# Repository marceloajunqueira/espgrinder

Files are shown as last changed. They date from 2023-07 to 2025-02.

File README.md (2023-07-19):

# Espgrinder

Espgrider is a kit to convert your manual coffee grinder into electric using very cheap parts. The software is based on the powefull ESPHome project.

The main goal is to convert very good manual coffee grinder into 2 in 1 Grind by Weight hardware. Also the hardware need to be used without any risk of demage, simulating the same torque and force used in hand grinding.

The motor is the "Mabuchi" standard that is commom used for car power window.

**There are two versions available:**
1. Without eletronics: Just the base with an On/Off switch, simple and direct. You only need a 3D printer and some soldering skills
2. Eletronic controlled by ESP32: The magic of software, with the eletronic you will be able to control speed, timer and even have a precise digital scale.

** Features for the electronic version**
1. Simple User Interface using SSD1306 display
2. PWM motor control
3. Timer to control grind speed
4. Precision digital scale
5. Over the Air firmware updates
6. Grind by Weight (Under development)

**Supported Grinders:**
You can use any grinder with 1/4 Hex shaft, only the support need to be adjusted
Included supports for:
 - Kingrinder K4 / K6

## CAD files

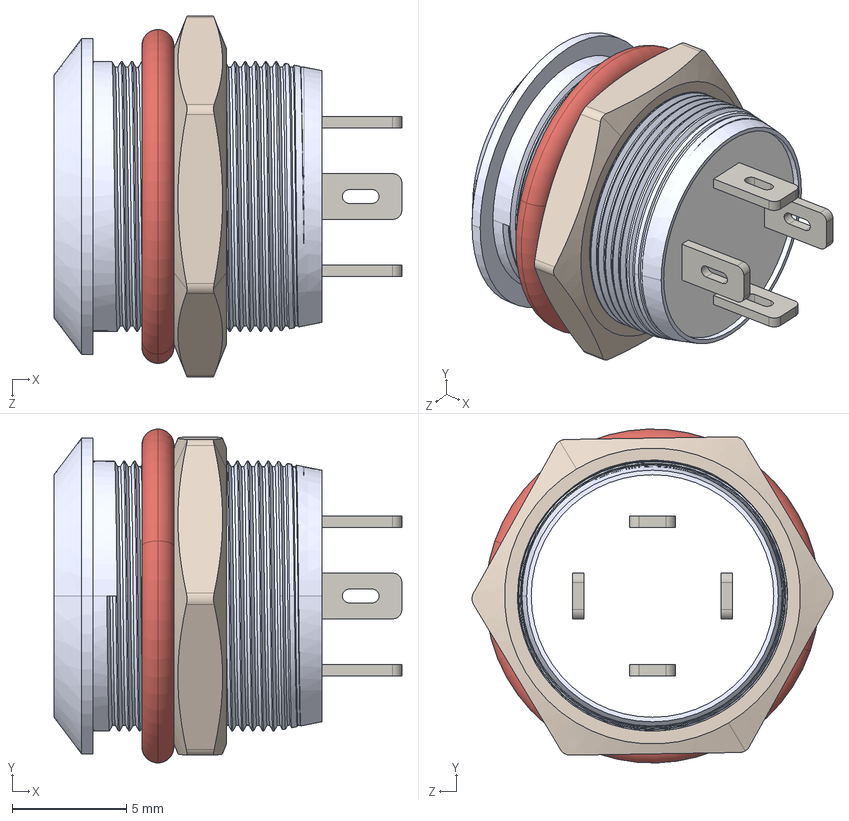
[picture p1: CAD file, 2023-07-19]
3D Model/Components/Push_btn_asm.STEP
15.2 x 14.6 x 15.8 mm
Push_btn
Push_btn_nut
Sealing_ring

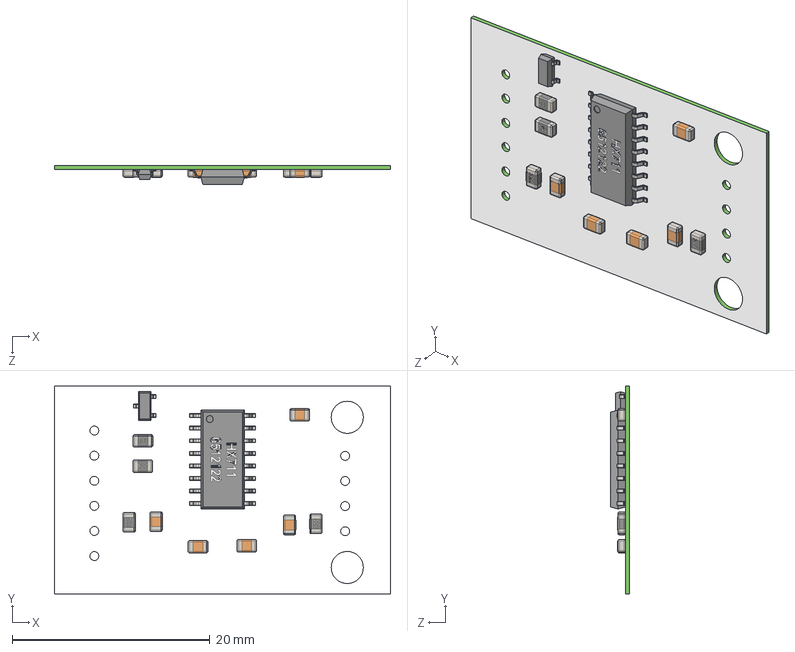
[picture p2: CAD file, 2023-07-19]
3D Model/Components/HX711.STEP
34.0 x 21.0 x 1.97 mm
placa_Valor predeterminado
base_HX711_Valor predeterminado
pino_HX711_Valor predeterminado x 16
RESISTOR_SMD_122_Valor predeterminado x 2
RESISTOR_SMD_822_Valor predeterminado
RESISTOR_SMD_203_Valor predeterminado
CAPACITOR_805_Valor predeterminado x 5
TRANSISTOR_SOT23_Valor predeterminado
PINO_SOT23_Valor predeterminado x 3

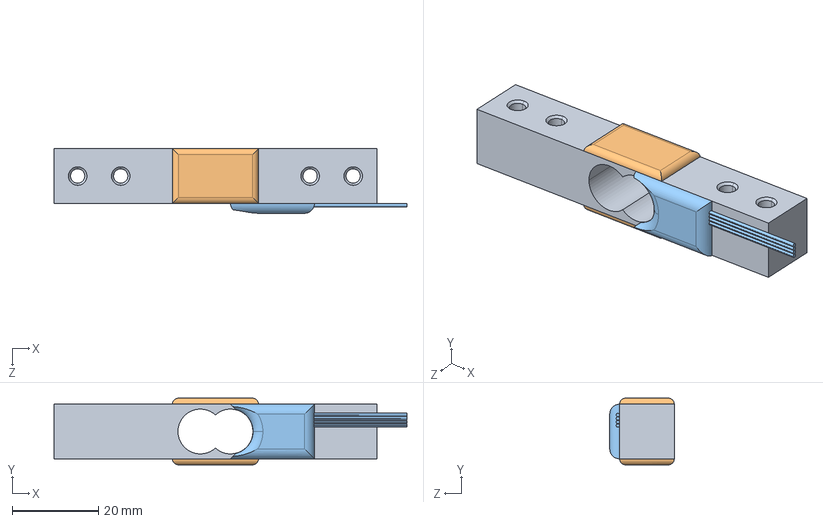
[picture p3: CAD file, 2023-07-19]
3D Model/Components/load cell.STEP
82.0 x 15.5 x 15.0 mm

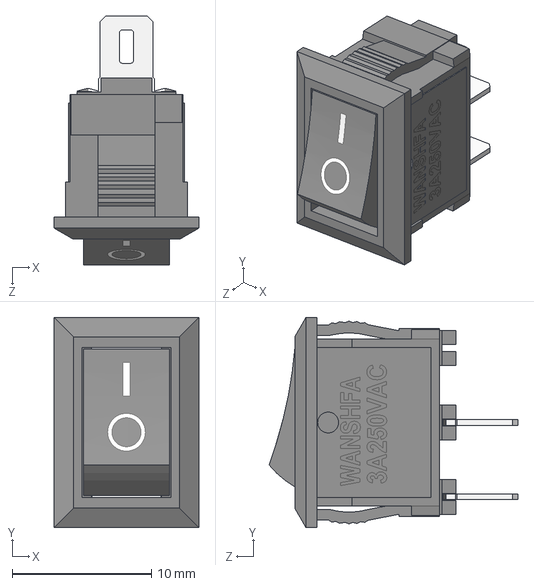
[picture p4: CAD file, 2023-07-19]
3D Model/Components/kcd11.STEP
10.4 x 15.1 x 17.9 mm

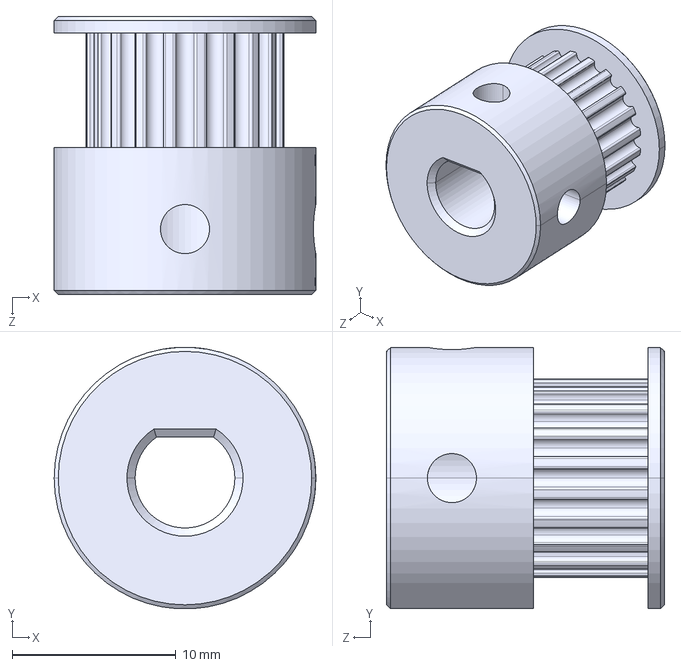
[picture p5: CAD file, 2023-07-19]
3D Model/Components/GT2 Pulley 20 Tooth (ID6mm).STEP
16.0 x 16.0 x 17.0 mm

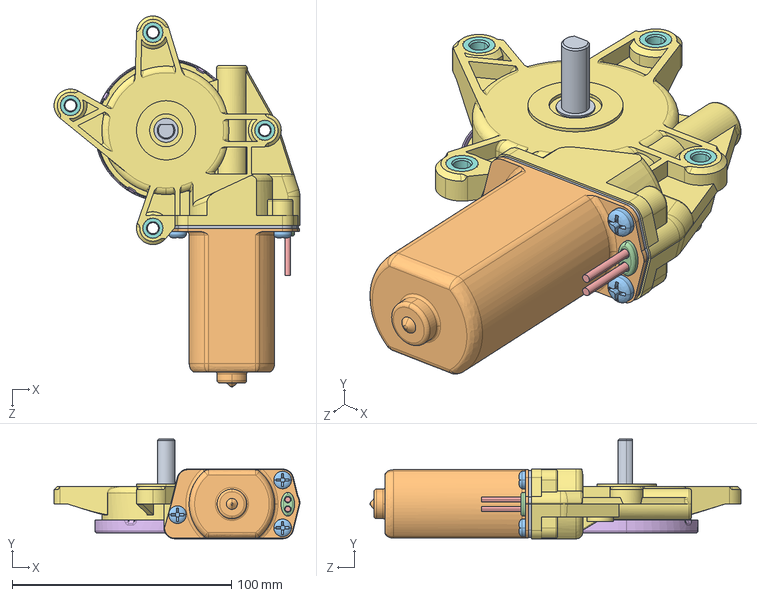
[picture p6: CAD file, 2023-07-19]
3D Model/Components/mabuchi.STEP
112.1 x 45.4 x 169.1 mm

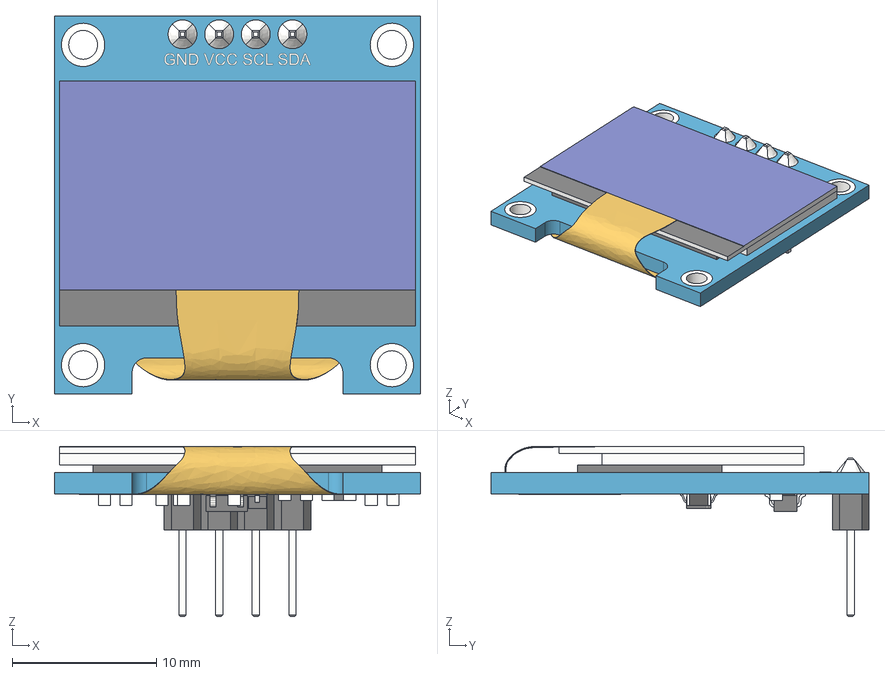
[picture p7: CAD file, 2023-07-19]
3D Model/Components/SSD1306_OLED_Display(128x64).step
25.4 x 26.2 x 11.8 mm
board
screen
pin_header
soldering
smd_capacitor
smd_capacitor (1)
914_smd_resistor
472_smd_resistor x 3
t4_smd_diode
smd_capacitor (2)
smd_capacitor (3)
smd_capacitor (4)
smd_capacitor (5)
smd_capacitor (6)
472_smd_resistor (1)
SOT-23_XC6206 v3
smd_capacitor (7)
flat_cable

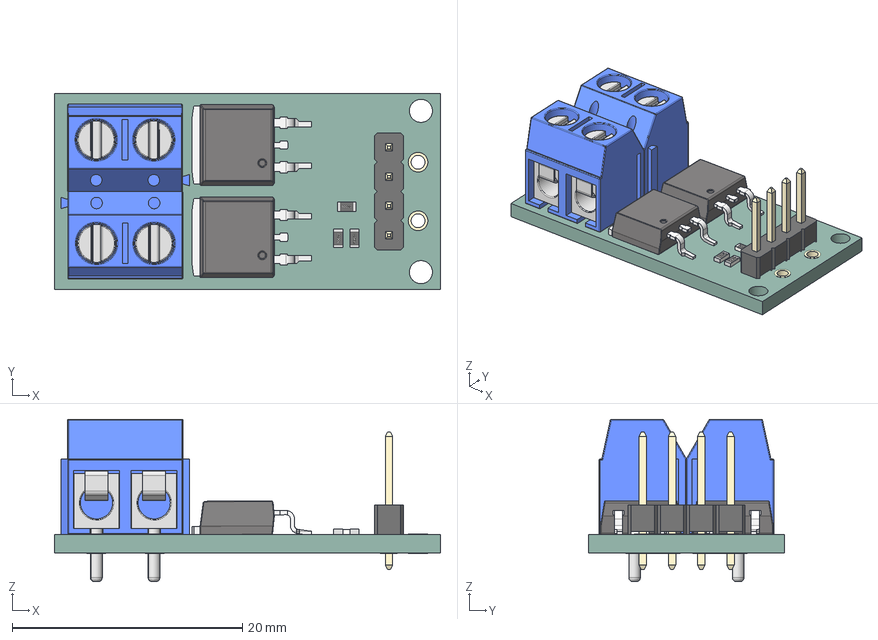
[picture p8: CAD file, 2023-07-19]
3D Model/Components/PWM Mosfet Modul 400W.step
33.5 x 17.0 x 14.1 mm
r-smd-0603 x 3
PinHeader
MOS x 2
tb5p-2p_p5_l10_w7-6_h10 v1 x 2

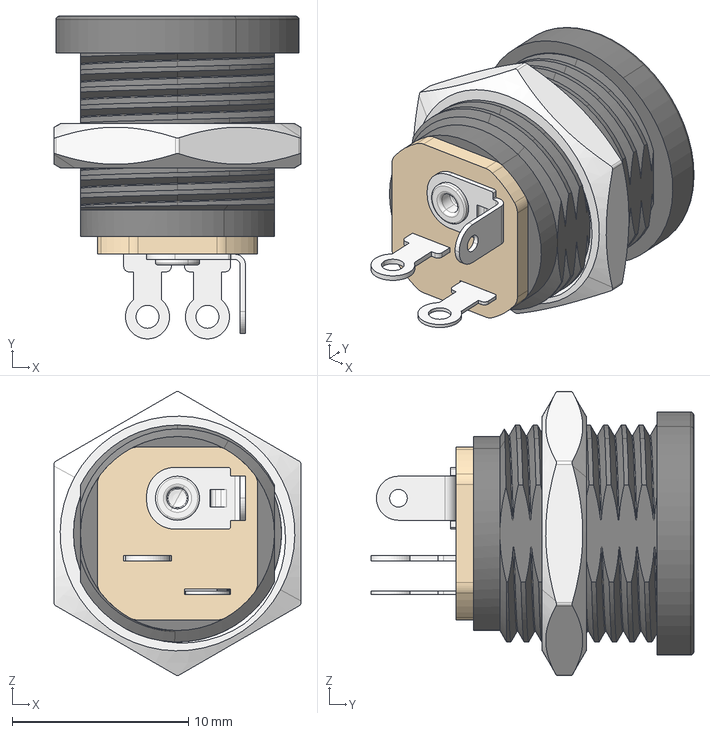
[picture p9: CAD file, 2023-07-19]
3D Model/Components/Connector_5,5-2,5_DS-223A.stp
14.0 x 18.3 x 16.1 mm

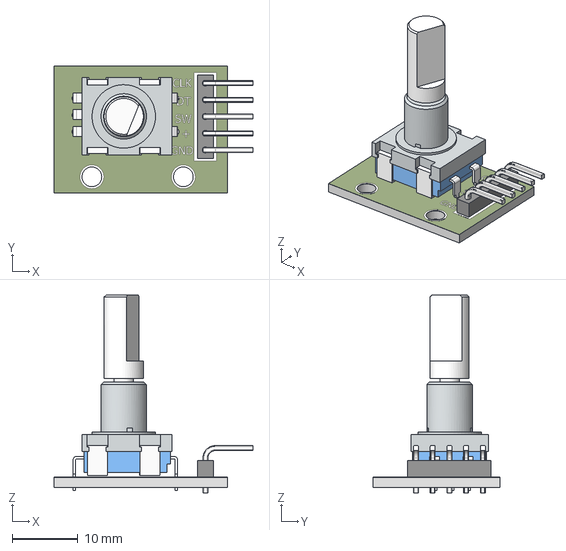
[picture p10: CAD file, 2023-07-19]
3D Model/Components/rotary encoder_chesr_2013.stp
30.3 x 19.3 x 30.1 mm

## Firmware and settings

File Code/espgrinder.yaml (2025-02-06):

esphome:
  name: espgrinder
  on_boot:
    priority: 600
    then:
      - lambda: |-
          id(motor).make_call().set_brightness(id(default_speed)).perform();
      - delay: 2s
      - lambda: |-
          id(tare_button).press();
          id(starting_up) = 0;
          if(id(working_mode) == 2){
            id(motor).turn_on().perform();
          }

esp8266:
  board: d1_mini
  restore_from_flash: true

# Enable logging
logger:
  level: INFO

wifi:
  ssid: "Ornitorrinco"
  password: "148casa45"
  #manual_ip:
    #static_ip: 192.168.1.122
    #gateway: 192.168.1.1
    #subnet: 255.255.255.0

ota:
  - platform: esphome
api:
 
web_server:
  port: 80

preferences:
  flash_write_interval: 5sec

globals:
  - id: display_page
    type: int
    restore_value: no
    initial_value: '1'
    
  - id: working_mode
    type: int
    restore_value: yes
    initial_value: '1'
    
  - id: starting_up
    type: int
    restore_value: no
    initial_value: '1'
    
  - id: default_speed
    type: float
    restore_value: yes
    initial_value: '1'
    
  - id: tare
    type: float
    restore_value: no
    initial_value: '0'
    
  - id: stopwatch_begin
    type: long
    restore_value: no
    initial_value: '0'
    
  - id: last_stopwatch
    type: long
    restore_value: no
    initial_value: '0'

# Buttons
 
button:
  ## Button used to initiate a manual tare
  - platform: template
    id: tare_button
    name: "Smart Scale Manual Tare Action"
    icon: mdi:scale-balance
    on_press:
      - lambda: |-
          id(tare) = id(scale).state;

binary_sensor:
  - platform: gpio
    pin:
      number: D5
      mode: INPUT_PULLUP
      inverted: True
    name: "WB1"
    on_click:
      - min_length: 50ms
        max_length: 350ms
        then:
          - button.press: tare_button
      - min_length: 500ms
        max_length: 3000ms
        then:
          lambda: |-
            if(id(display_page) < 4) {
              id(display_page) += 1;
            } else {
              id(display_page) = 1;
            }
        
  - platform: gpio
    pin:
      number: D0
      inverted: true
    name: "WB2"
    filters:
       - delayed_on: 10ms
    on_click:
      min_length: 50ms
      then:
        - light.toggle: motor
 
sensor:
# ------------ Scale --------------
    
  - platform: hx711
    id: scale_raw
    name: "Scale Raw"
    internal: False
    dout_pin: D4
    clk_pin: D3
    gain: 128
    update_interval: 0.1s
    filters:
      - quantile:
          window_size: 5
          send_every: 1
          send_first_at: 1
          quantile: .9
    on_value:
      then:
        - sensor.template.publish:
            id: scale
            state: !lambda 'return id(scale_raw).state;'
                        
  # Mapped value to Grams
  - platform: template
    id: scale
    name: "scale"
    internal: False
    filters:
      - lambda: 'return x;'
      - calibrate_linear:
          # retrieve these values by evaluating the raw values with loads of known mass.
          # note that a bigger difference between measurements usually results in higher resolution,
          # so measure 0 Kg and the highest known mass you have (like f.ex. your own weight, measured by a normal scale with good accuracy)
          - -2943 -> 0
          - -832880 -> 428.9
      - lambda: |-
          if (x <= 2 && x >= -2 ) {
            return 0.0;
          } else {
            return x;
          }
    unit_of_measurement: 'g'
    accuracy_decimals: 1
    # the sensor will automatically update through the 'sensor.template.publish' call
    update_interval: never
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
